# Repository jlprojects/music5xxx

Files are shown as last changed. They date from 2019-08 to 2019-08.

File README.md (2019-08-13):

# music5xxx
## Hybrid Music 5000/3000 BBC Microcomputer synthesiser clone PCB 

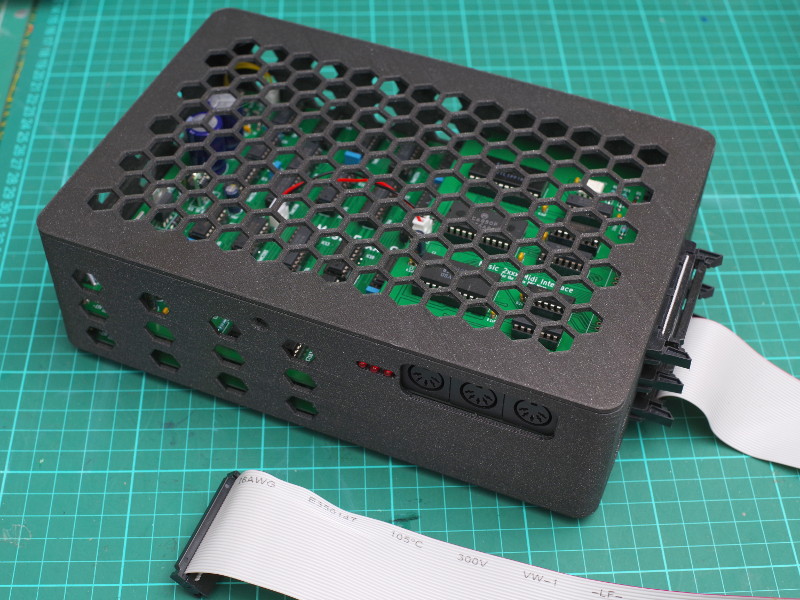
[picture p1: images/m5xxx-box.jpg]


This is a hardware clone of the Hybrid Music 5000 add-on for the BBC Microcomputer model B and Master 128. It was designed by Chris Jordan in 1984 as the Acorn Music500, and became part of quite an advanced (for its time) music recording and programming system. It was available for sale until at least 1992. Second hand models appear from time-to-time on eBay, but appear quite rare.

The unit connects to the BBC Microcomputer's 1Mhz bus, and implements an 8 voice, 16 channel, 8 bit stereo wavetable-style synthesizer. It uses a companding DAC to increase the fidelity of using 8 bit waveforms. The PCB can be configured as an expander, allowing two to be connected to the computer, doubling the available voices and channels.

## The clone

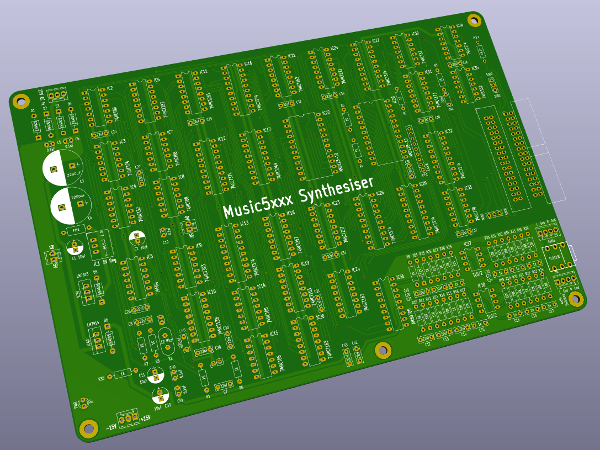
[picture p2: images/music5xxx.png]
music5xxx PCB render


It is designed in Kicad, using the original schematic and photographs of the original unit. PCBs have been made, and tested using a BBC Microcomputer Model B and BBC Master 128.

Currently all the 74xx series logic ICs are available new. Two 9128-10 RAM ICs, and the AM6070DC Companding DAC are no longer manufactured, but are available as NOS from Utsource https://www.utsource.net/ and perhaps other places.

Some alterations were made compared to the original unit:

* The power supply circuit has been changed for safety reasons, as the original unit used an on-board mains transformer. This is replaced by a 15V AC-AC plug-top adapter, and the +15V/-15V and 5V DC rails are generated from the 15V AC input. A LM7805 compatible switching DC-DC converter is used for the 5V rail, and saves having to use a heatsink if a linear adapter was used.

* Originally, the Music5000 used 74LS series logic ICs - experimentation has shown that 74HCT and 74HC series logic ICs can be used and work well with the circuit, with the advantage that they are more power efficient and run much cooler.

* The audio output DIN socket has been replaced with a 3.5mm stereo socket for convenience.

* The PCB can be configured using jumpers to work both as a Music5000 and Music3000 expander, allowing two PCBs to be stacked together sharing the same power supply.

* The low-pass filter in the output stage has been altered to not be so aggressive, possibly at the expense of unmasking some digital hash when using some instruments.

## Resources

* A comprehensive archive about the Hybrid Music System: https://www.retro-kit.co.uk/page.cfm/content/Hybrid-Music-5000-Synthesiser/

* The Stardot 8bit hardware forum often has posts about the Hybrid Music system: https://stardot.org.uk/forums/viewforum.php?f=3

* Here's the Stardot thread about this project: https://stardot.org.uk/forums/viewtopic.php?f=3&t=16895

## Other options

Instead of building one of these, you could use the emulated version that's included with Beebem: https://github.com/stardot/beebem-windows

Or if you want to use a real BBC Microcomputer you could make one of these:

* Hoglet's 1Mhz Bus->FPGA adapter which implements the Music5000/3000 in an FPGA module: https://stardot.org.uk/forums/viewtopic.php?f=3&t=16643

* dp11's 1Mhz Bus->Raspberry Pi adapter which emulates the Music5000 on a Raspberry Pi: https://stardot.org.uk/forums/viewtopic.php?f=3&t=15848

## Licence

Unless otherwise marked, work in this repository is licenced under [Creative Commons Attribution-ShareAlike 4.0 International License](http://creativecommons.org/licenses/by-sa/4.0/)

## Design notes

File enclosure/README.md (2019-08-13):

# music5xxx
## Hybrid Music 5000/3000/2000 BBC Microcomputer synthesiser clone project enclosure  

This is a design for a 3d printed enclosure for the clone Music5000 system. It is designed using Fusion360. STL files are provided for printing, as well as a Fusion360 file for modification.

music5xxx PCB render

It is designed for 3 PCBs separated using 15mm brass M-F spacers. The lowest PCB is configured as an M3000 module without the power supply components. The middle PCB is configured as a M5000 module. PCB headers and pins connect power between the two lower PCBs. The upper PCB is a [M2xxx Midi module](https://github.com/jlbeebprojects/music2xxx). A pair of wires connect to the 5V header on the M5000 PCB. 

I printed mine using 0.3mm layer height using PLA plastic. Make sure you have good bed adhesion to prevent warping due to the large flat contact areas. Note the design includes thin support struts to support the 1Mhz port and Midi output apertures. Clip these off before assembling the unit.

Insert and tighten the 15V AC power socket before installing the PCBs. 

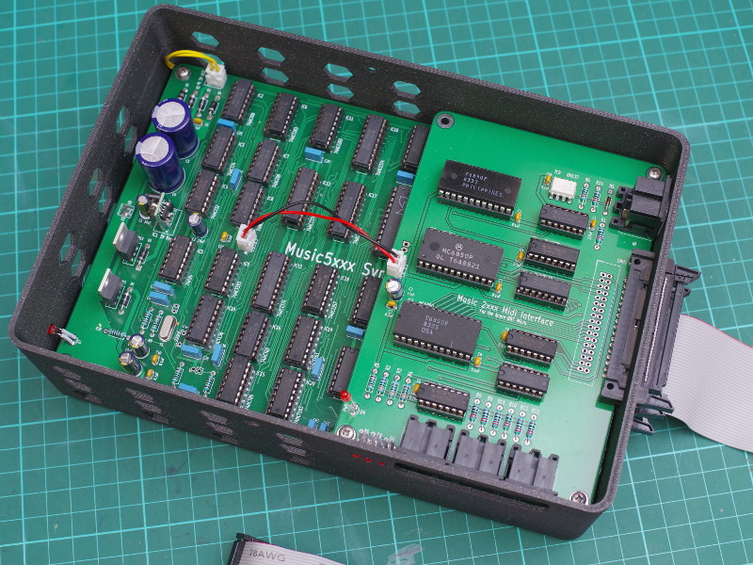
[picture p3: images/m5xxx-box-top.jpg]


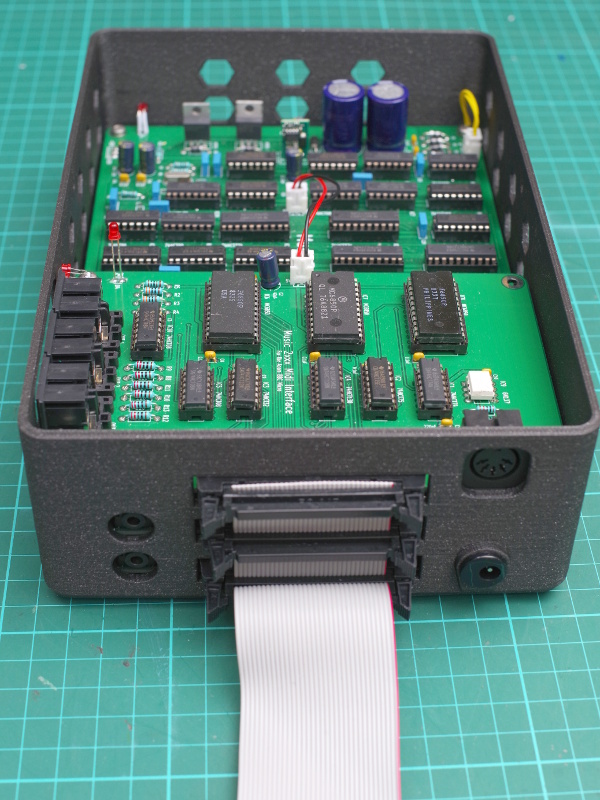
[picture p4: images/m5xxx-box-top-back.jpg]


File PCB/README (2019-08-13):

## Music 5xxx clone PCB

Made using Kicad 5.1.2

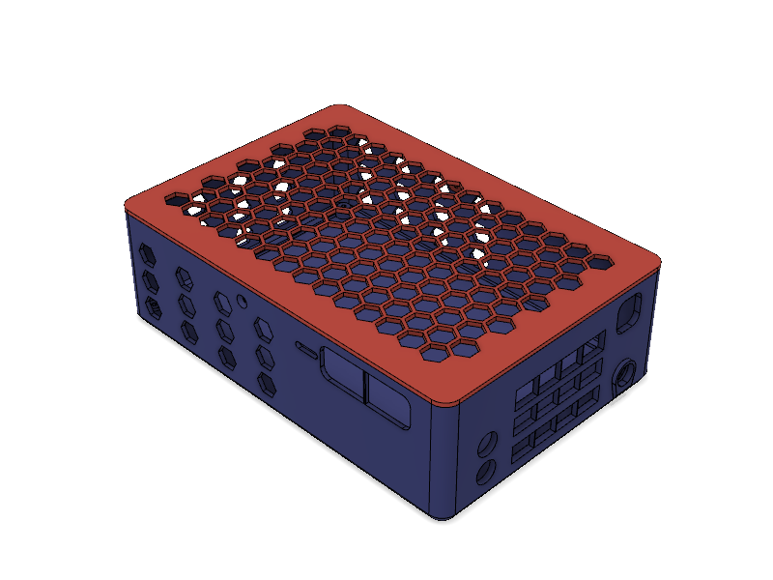
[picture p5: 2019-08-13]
enclosure/M5xxx-box.png

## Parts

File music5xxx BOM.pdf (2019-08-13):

music5xxx

## Music5xxx PCB BOM

Quantity Designation | Designator | Notes

Resistors
16 | 1K
1 | 4K7 | R37
21 | 15K
1 | 1Kx8 | RP1 | 9 pin resistor array, commoned

Capacitors
5 | 0.1uF | C5, C6, C10, C40, C41 | Ceramic: 2.5mm lead pitch
8 | 1n | C15, C16, C17, C18, C21, C22, C23, C24 Film: 5mm lead pitch
23 | 22nF | | Film: 5mm lead pitch
4 | 10uF | C1, C2, C11, C39 | Electrolytic 2.5mm lead pitch
2 | 2200uF | C3, C4 | Electrolytic 7.5mm lead pitch
Note: C9 (33pf, C44, C45 (220nF) not fitted

Diodes
6 | 1N4001 | D5, D6, D3, D4, D2, D1 | DO41
1 | PWR | D7 | 3mm LED
1 | 12V Zener Diode ZD1 | DO35

Integrated Circuits
1 | 74HCT00 | IC14
1 | 74F04 | IC5
3 | 74HCT08 | IC2, IC7, IC8
1 | 74HCT30 | IC33
3 | 74HCT32 | IC4, IC30, IC35
2 | 74HCT74 | IC33, IC33
1 | 74HCT86 | IC15
1 | 74HCT138 | IC10
4 | 74HCT163 | IC19, IC20, IC21, IC24
2 | 74HCT173 | IC15, IC31
1 | 74HCT244 | IC17
2 | 74HCT257 | IC18, IC23
2 | 74HCT283 | IC6, IC11
7 | 74HCT374
1 | 74HCT393 | IC9
2 | TL072 | IC37, IC38
1 | AM6070D | IC36
1 | R-78E5.0-1.0 | IC1
1 | LM7815 | IC39 | +15V Voltage regulator
1 | LM7915 | IC40 | -15V Voltage regulator
2 | AM9128-10 | IC22, IC28 | Memory IC

R1, R2, R3, R4, R5, R6, R7, R8, R9, R13, R15, R21, R25, R27, R33, R38

Standard 1% metal film through hole resistors

R10, R11, R12, R14, R16, R17, R18, R19, R20, R22, R23, R24, R26, R28, R29, R30, R31, R32, R34, R35, R36

C7, C8, C12, C13, C14, C19, C20, C25, C26, C27, C28, C29, C30, C31, C32, C33, C34, C35, C36, C37, C38, C42, C43

IC12, IC13, IC16, IC26, IC27, IC29, IC32

DC-DC converter – 1A, 7805 pinout switching module

music5xxx

IC Sockets
2 | 8 Way | 7.62mm wide
13 | 14 Way | 7.62mm wide
11 | 16 Way | 7.62mm wide
1 | 18 Way | 7.62mm wide
8 | 20 Way | 7.62mm wide
2 | 24 Way | Wide 15.24mm

Connectors – Molex KK/JST XH or similar
2 | J2, J3 | 2 way
1 | J1, J4 | 3 way
1 | J5, J6

1Mhz Bus connectors
1 | 1MHzBus1 | J11
1 | 1MHzBus2 | J12 IDC plugs for 1Mhz bus connection

Jack sockets
1 | FCR1295 | J7
1 | | Not on PCB

Misc
1 | 12 Mhz Crystal | X1 | Crystal HC49 Through hole
1 | Ferrite | FB1
13 | | 15mm hex standoffs, M3, male-female | Used for stacking boards

4 way – optional if using audio jack only

34 way (2x17) 2.54mm Straight IDC Header (use if connecting
extender/midi)
34 way (2x17) 2.54mm Angled IDC Header for 1Mhz Bus connection

34 way ribbon cable for 1Mz bus connection

Cliff FCR1295 stereo jack socket PCB mount
2.1mm panel
mount socket

Or suitable panel mount socket for 15V AC connection

Or use wire link. Ferrite helps isolate switcher supply noise.

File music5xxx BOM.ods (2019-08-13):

Music5xxx PCB BOM
Quantity | Designation | Designator | Notes
Resistors
16 | 1K | R1, R2, R3, R4, R5, R6, R7, R8, R9, R13, R15, R21, R25, R27, R33, R38 | Standard 1% metal film through hole resistors
1 | 4K7 | R37
21 | 15K | R10, R11, R12, R14, R16, R17, R18, R19, R20, R22, R23, R24, R26, R28, R29, R30, R31, R32, R34, R35, R36
1 | 1Kx8 | RP1 | 9 pin resistor array, commoned
Capacitors
5 | 0.1uF | C5, C6, C10, C40, C41 | Ceramic: 2.5mm lead pitch
8 | 1n | C15, C16, C17, C18, C21, C22, C23, C24 | Film: 5mm lead pitch
23 | 22nF | C7, C8, C12, C13, C14, C19, C20, C25, C26, C27, C28, C29, C30, C31, C32, C33, C34, C35, C36, C37, C38, C42, C43 | Film: 5mm lead pitch
4 | 10uF | C1, C2, C11, C39 | Electrolytic 2.5mm lead pitch
2 | 2200uF | C3, C4 | Electrolytic 7.5mm lead pitch
 |  | Note: C9 (33pf, C44, C45 (220nF) not fitted
Diodes
6 | 1N4001 | D5, D6, D3, D4, D2, D1 | DO41
1 | PWR | D7 | 3mm LED
1 | 12V Zener Diode | ZD1 | DO35
Integrated Circuits
1 | 74HCT00 | IC14
1 | 74F04 | IC5
3 | 74HCT08 | IC2, IC7, IC8
1 | 74HCT30 | IC33
3 | 74HCT32 | IC4, IC30, IC35
2 | 74HCT74 | IC33, IC33
1 | 74HCT86 | IC15
1 | 74HCT138 | IC10
4 | 74HCT163 | IC19, IC20, IC21, IC24
2 | 74HCT173 | IC15, IC31
1 | 74HCT244 | IC17
2 | 74HCT257 | IC18, IC23
2 | 74HCT283 | IC6, IC11
7 | 74HCT374 | IC12, IC13, IC16, IC26, IC27, IC29, IC32
1 | 74HCT393 | IC9
2 | TL072 | IC37, IC38
1 | AM6070D | IC36
1 | R-78E5.0-1.0 | IC1 | DC-DC converter – 1A, 7805 pinout switching module
1 | LM7815 | IC39 | +15V Voltage regulator
1 | LM7915 | IC40 | -15V Voltage regulator
2 | AM9128-10 | IC22, IC28 | Memory IC
IC Sockets
2 | 8 Way | 7.62mm wide
13 | 14 Way | 7.62mm wide
11 | 16 Way | 7.62mm wide
1 | 18 Way | 7.62mm wide
8 | 20 Way | 7.62mm wide
2 | 24 Way | Wide 15.24mm
Connectors – Molex KK/JST XH or similar
2 |  | J2, J3 | 2 way
1 |  | J1, J4 | 3 way
1 |  | J5, J6 | 4 way – optional if using audio jack only
1Mhz Bus connectors
1 | 1MHzBus1 | J11 | 34 way (2x17) 2.54mm Straight IDC Header (use if connecting extender/midi)
1 | 1MHzBus2 | J12 | 34 way (2x17) 2.54mm Angled IDC Header for 1Mhz Bus connection
 |  | IDC plugs for 1Mhz bus connection
 |  | 34 way ribbon cable for 1Mz bus connection
Jack sockets
1 | FCR1295 | J7 | Cliff FCR1295 stereo jack socket PCB mount
1 | 2.1mm panel mount socket | Not on PCB | Or suitable panel mount socket for 15V AC connection
Misc
1 | 12 Mhz Crystal | X1 | Crystal HC49 Through hole
1 | Ferrite | FB1 | Or use wire link. Ferrite helps isolate switcher supply noise.
13 |  | 15mm hex standoffs, M3, male-female | Used for stacking boards

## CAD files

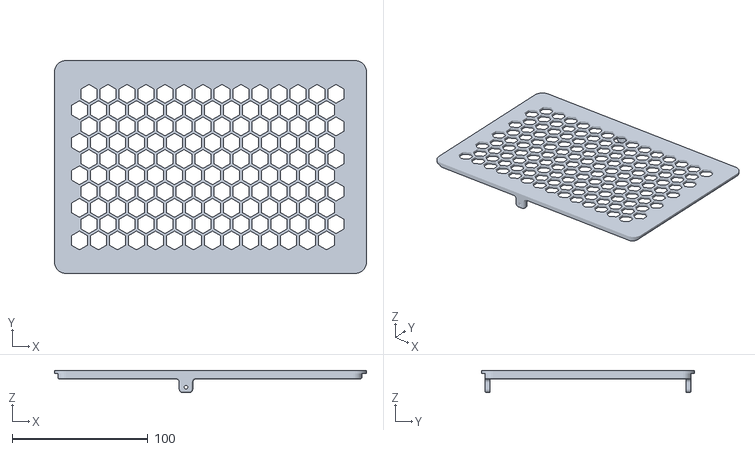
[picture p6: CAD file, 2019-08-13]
enclosure/M5xxx-lid.stl
229.8 x 156.8 x 16.4

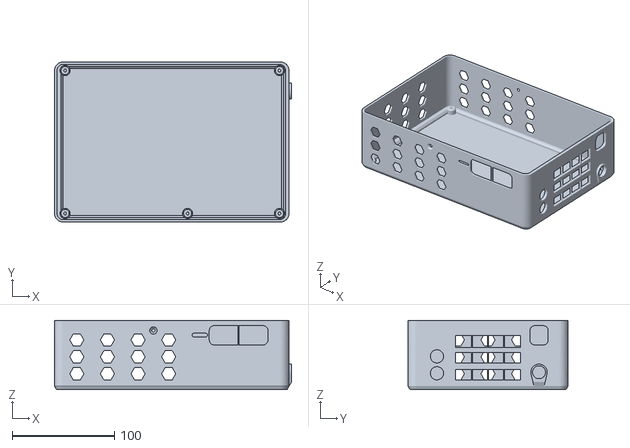
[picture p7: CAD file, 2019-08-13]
enclosure/M5xxx-base.stl
232.2 x 156.8 x 68.0

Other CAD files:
enclosure/M5xxx.f3d

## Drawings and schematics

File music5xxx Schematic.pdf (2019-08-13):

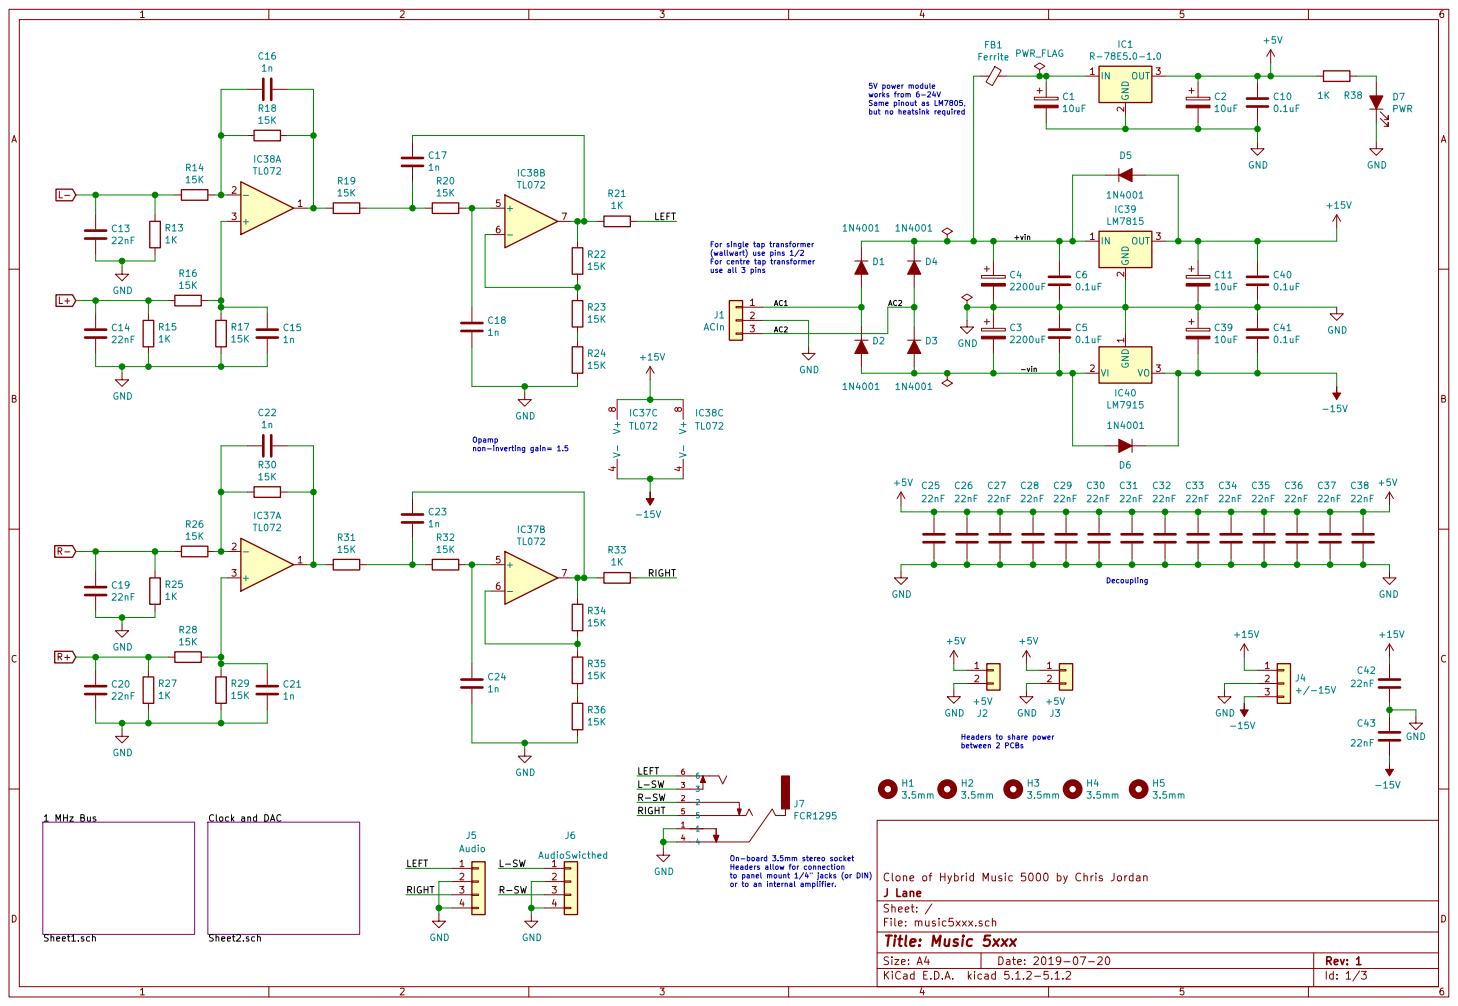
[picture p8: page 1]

Same pinout as LM7805, but no heatsink required +5V GND

5V power module works from 6-24V

For single tap transformer
(wallwart) use pins 1/2 For centre tap transformer use all 3 pins1

to panel mount 1/4" jacks (or DIN) or to an internal amplifier.

File: music5xxx.sch Sheet: / J Lane Clone of Hybrid Music 5000 by Chris Jordan

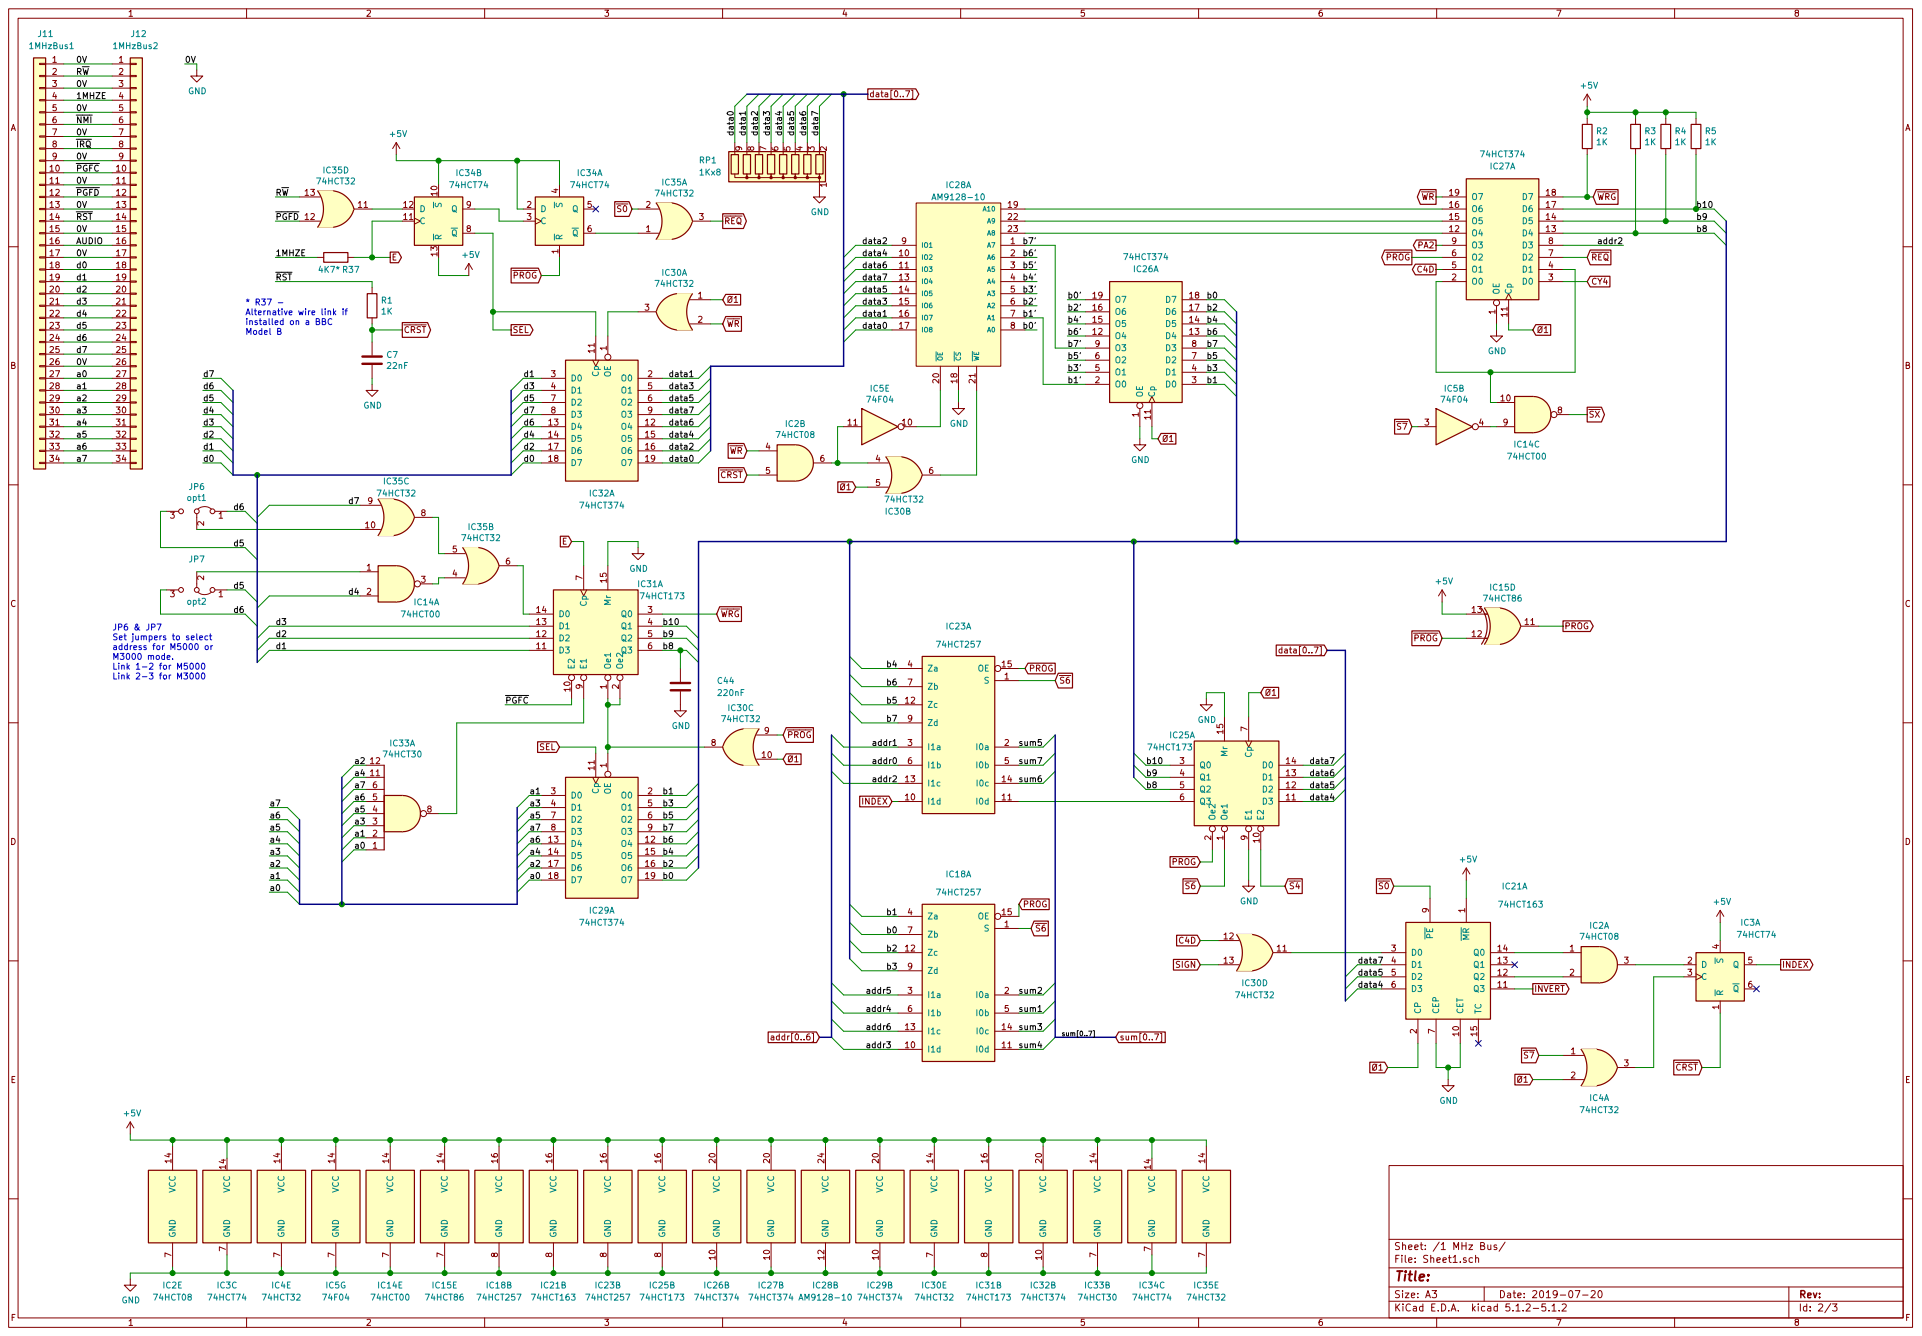
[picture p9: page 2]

* R37 - Alternative wire link if

installed on a BBC Model B

JP6 & JP7 Set jumpers to select address for M5000 or M3000 mode. Link 1-2 for M5000

Id: 2/3 Title: File: Sheet1.sch Sheet: /1 MHz Bus/

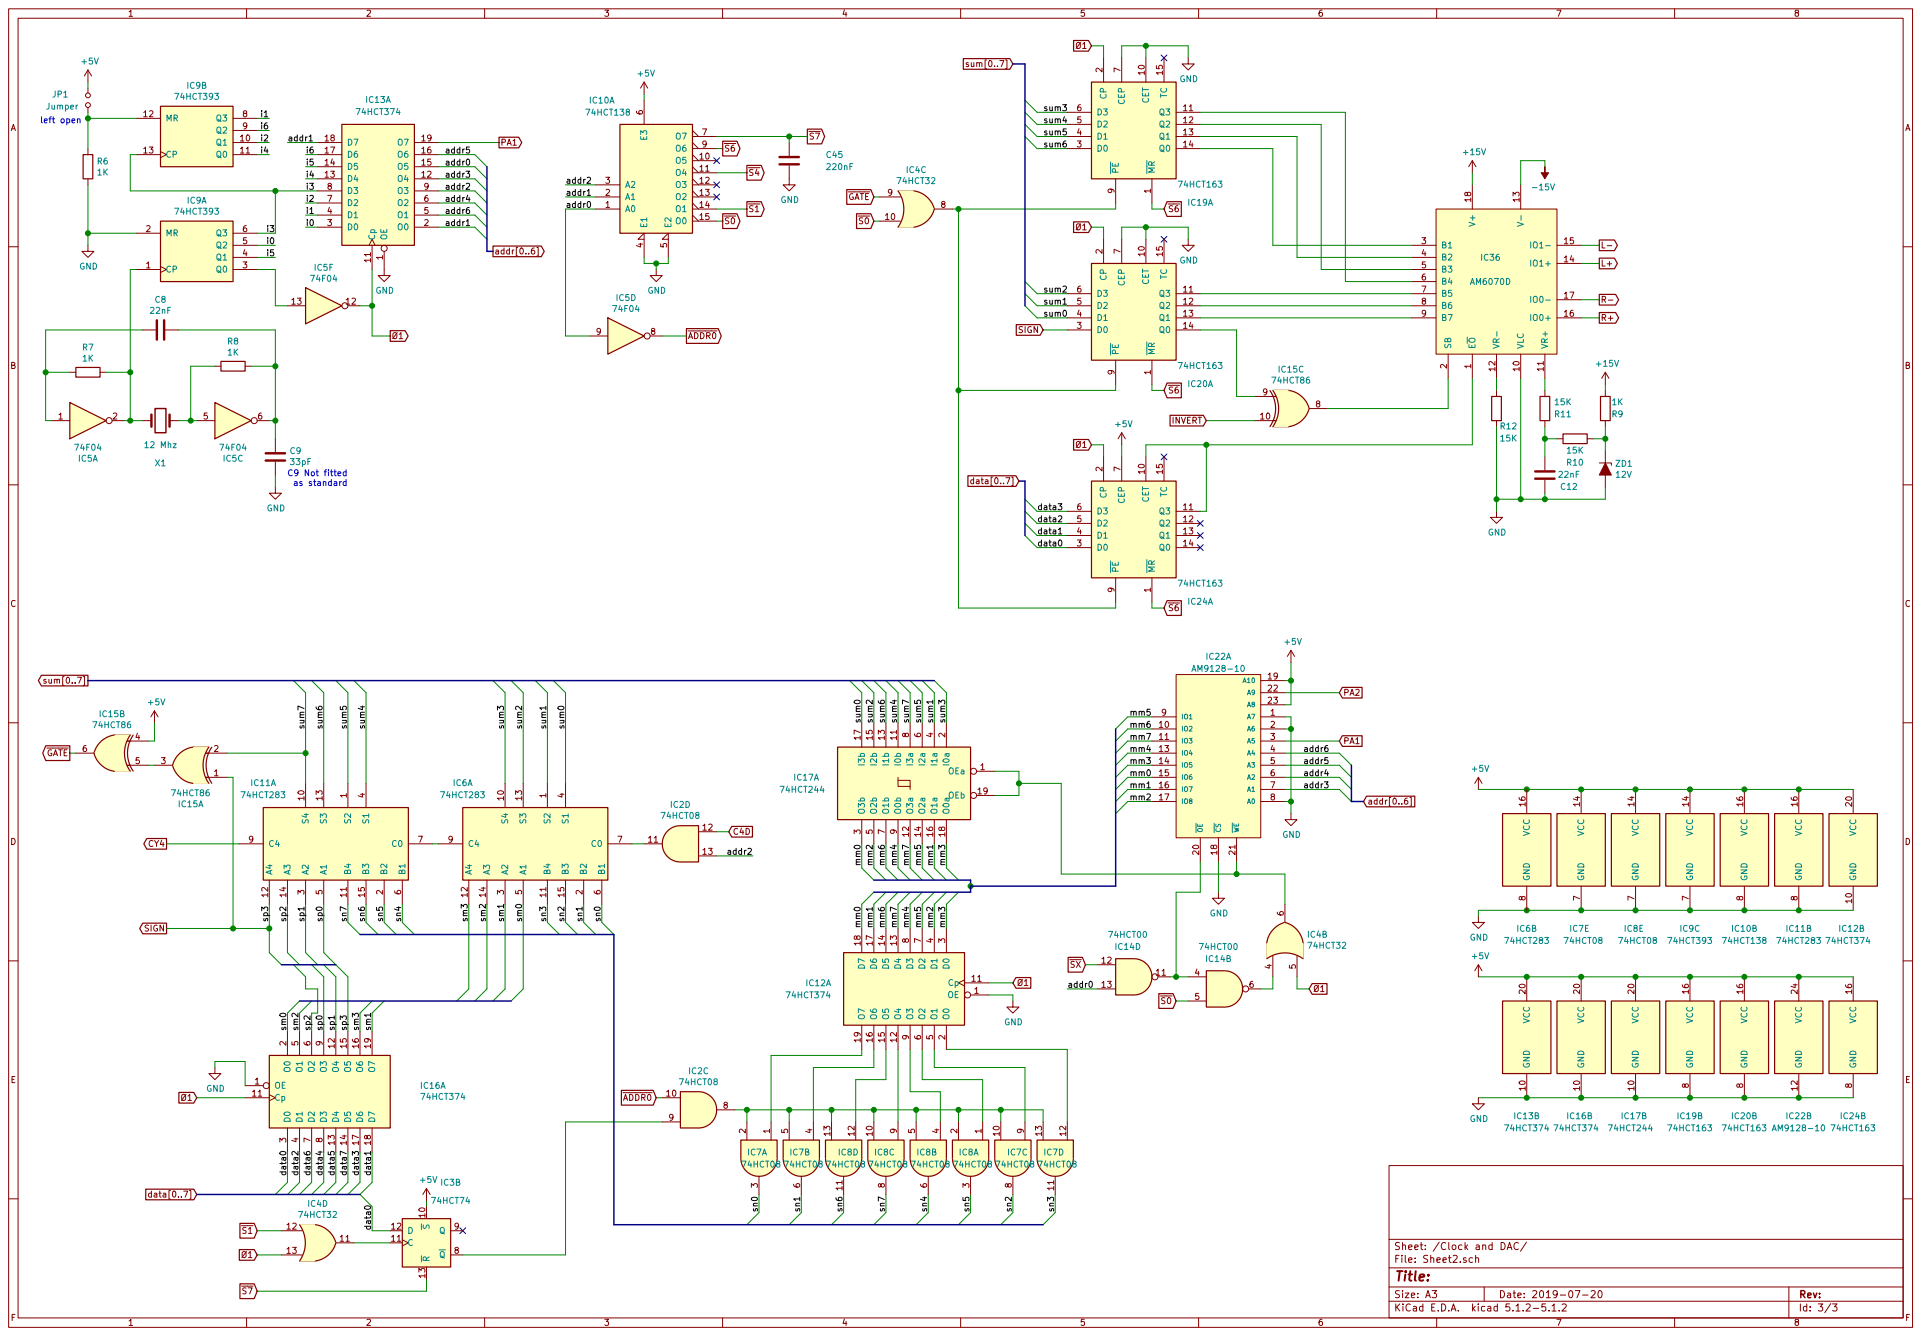
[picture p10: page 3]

Id: 3/3 Title: File: Sheet2.sch Sheet: /Clock and DAC/

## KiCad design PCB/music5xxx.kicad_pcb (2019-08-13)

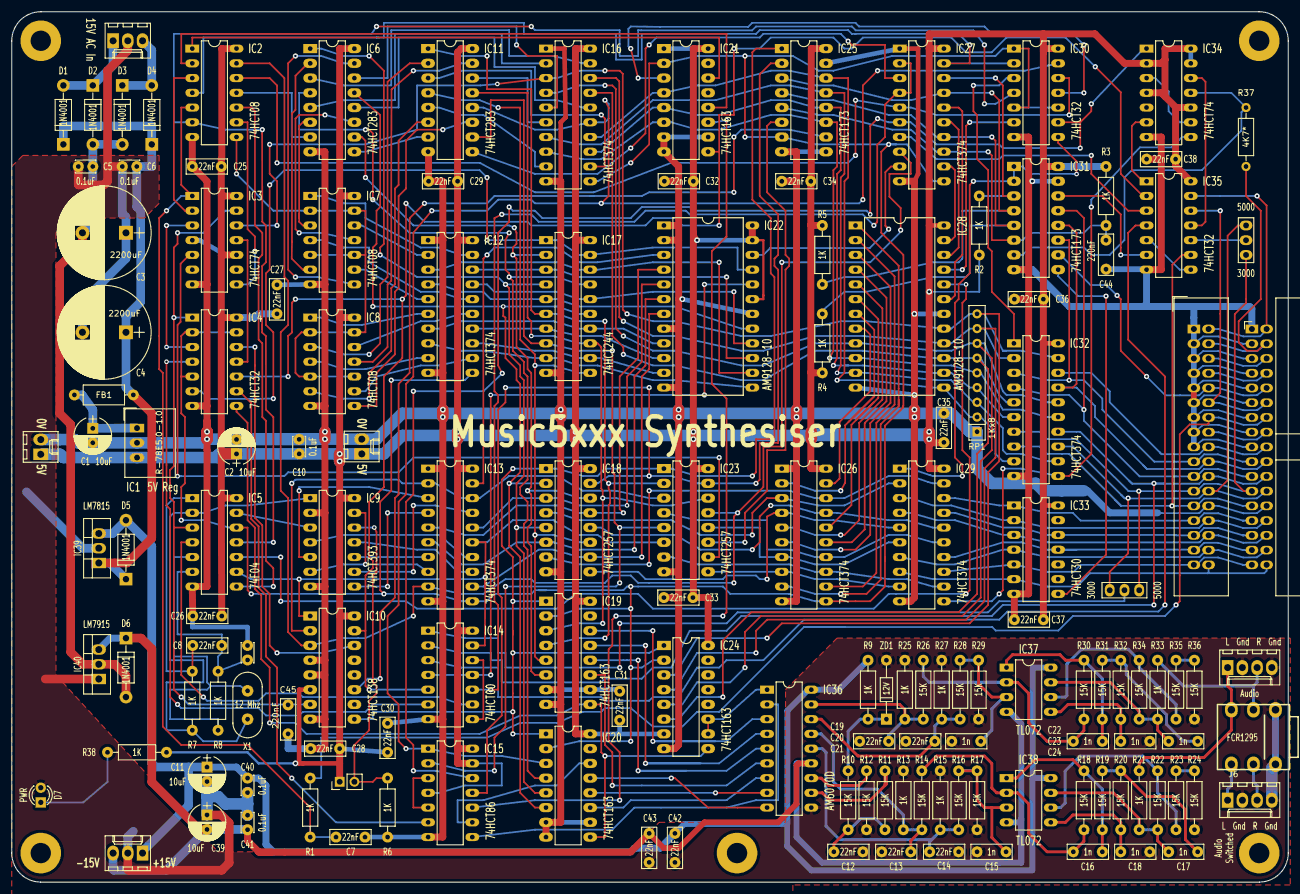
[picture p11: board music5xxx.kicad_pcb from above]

Board: 2 copper layers, 220.0 x 150.0 mm, 151 parts (0 on the bottom side), 217 nets.

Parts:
C1, C2, C11, C39: 10uF; CP_Radial_D6.3mm_P2.50mm
C3, C4: 2200uF; CP_Radial_D16.0mm_P7.50mm
C5, C6, C10, C40, C41: 0.1uF; C_Disc_D3.4mm_W2.1mm_P2.50mm
C7, C8, C12, C13, C14, C19, C20, C25, C26, C27, C28, C29, C30, C31, C32, C33, C34, C35, C36, C37, C38, C42, C43: 22nF; C_Rect_L7.0mm_W2.5mm_P5.00mm
C9: 33pF; C_Disc_D3.4mm_W2.1mm_P2.50mm
C15, C16, C17, C18, C21, C22, C23, C24: 1n; C_Rect_L7.0mm_W2.5mm_P5.00mm
C44, C45: 220nF; C_Rect_L7.0mm_W2.5mm_P5.00mm
D1, D2, D3, D4, D5, D6: 1N4001; D_DO-41_SOD81_P10.16mm_Horizontal
D7: PWR; LED_D3.0mm
FB1: Ferrite; L_Axial_L7.0mm_D3.3mm_P10.16mm_Horizontal_Fastron_MICC
H1, H2, H3, H4, H5: 3.5mm; MountingHole_3.5mm_Pad
IC1: R-78E5.0-1.0; DCDC-Conv_RECOM_R-78E-0.5
IC2, IC7, IC8: 74HCT08; DIP-14_W7.62mm_LongPads
IC3, IC34: 74HCT74; DIP-14_W7.62mm_LongPads
IC4, IC30, IC35: 74HCT32; DIP-14_W7.62mm_LongPads
IC5: 74F04; DIP-14_W7.62mm_LongPads
IC6, IC11: 74HCT283; DIP-16_W7.62mm_LongPads
IC9: 74HCT393; DIP-14_W7.62mm_LongPads
IC10: 74HCT138; DIP-16_W7.62mm_LongPads
IC12, IC13, IC16, IC26, IC27, IC29, IC32: 74HCT374; DIP-20_W7.62mm_LongPads
IC14: 74HCT00; DIP-14_W7.62mm_LongPads
IC15: 74HCT86; DIP-14_W7.62mm_LongPads
IC17: 74HCT244; DIP-20_W7.62mm_LongPads
IC18, IC23: 74HCT257; DIP-16_W7.62mm_LongPads
IC19, IC20, IC21, IC24: 74HCT163; DIP-16_W7.62mm_LongPads
IC22, IC28: AM9128-10; DIP-24_W15.24mm_LongPads
IC25, IC31: 74HCT173; DIP-16_W7.62mm_LongPads
IC33: 74HCT30; DIP-14_W7.62mm_LongPads
IC36: AM6070D; DIP-18_W7.62mm_LongPads
IC37, IC38: TL072; DIP-8_W7.62mm_LongPads
IC39: LM7815; TO-220-3_Vertical
IC40: LM7915; TO-220-3_Vertical
J1: ACIn; Molex_KK-6410-03_03x2.54mm_Straight
J2, J3: +5V; Molex_KK-6410-02_02x2.54mm_Straight
J4: +/-15V; Molex_KK-6410-03_03x2.54mm_Straight
J5: Audio; Molex_KK-6410-04_04x2.54mm_Straight
J6: AudioSwicthed; Molex_KK-6410-04_04x2.54mm_Straight
J7: FCR1295; Cliff-FCR1295
J11: 1MHzBus1; IDC-Header_2x17_Pitch2.54mm_Straight
J12: 1MHzBus2; IDC-Header_2x17_Pitch2.54mm_Angled
JP1: Jumper; Pin_Header_Straight_1x02_Pitch2.54mm
JP6: opt1; Pin_Header_Straight_1x03_Pitch2.54mm
JP7: opt2; Pin_Header_Straight_1x03_Pitch2.54mm
R1, R2, R3, R4, R5, R6, R7, R8, R9, R13, R15, R21, R25, R27, R33, R38: 1K; R_Axial_DIN0207_L6.3mm_D2.5mm_P10.16mm_Horizontal
R10, R11, R12, R14, R16, R17, R18, R19, R20, R22, R23, R24, R26, R28, R29, R30, R31, R32, R34, R35, R36: 15K; R_Axial_DIN0207_L6.3mm_D2.5mm_P10.16mm_Horizontal
R37: 4K7*; R_Axial_DIN0207_L6.3mm_D2.5mm_P10.16mm_Horizontal
RP1: 1Kx8; R_Array_SIP9
X1: 12 Mhz; Crystal_HC49-U_Vertical
ZD1: 12V; D_DO-35_SOD27_P10.16mm_Horizontal

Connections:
+5V: C2.1, C10.1, C25.1, C26.1, C27.1, C28.1, C29.1, C30.1, C31.1, C32.1, C33.1, C34.1, C35.1, C36.1, C37.1, C38.1, IC1.3, IC2.14, IC3.4, IC3.10, IC3.14, IC4.14, IC5.14, IC6.16, IC7.14, IC8.14, IC9.14, IC10.6, IC10.16, IC11.16, IC12.20, IC13.20, IC14.14, IC15.4, IC15.13, IC15.14, IC16.20, IC17.20, IC18.16, IC19.16, IC20.16, IC21.1, IC21.16, IC22.19, IC22.23, IC22.24, IC23.16, IC24.7, IC24.16, IC25.16, IC26.20, IC27.20, IC28.24, IC29.20, IC30.14, IC31.16, IC32.20, IC33.14, IC34.2, IC34.4, IC34.10, IC34.13, IC34.14, IC35.14, J2.1, J3.1, JP1.1, R2.1, R3.1, R4.1, R5.1, R38.1
+15V: C11.1, C40.1, C42.1, D5.2, IC36.18, IC37.8, IC38.8, IC39.3, J4.1, R9.2
-15V: C39.2, C41.2, C43.2, D6.1, IC36.13, IC37.4, IC38.4, IC40.3, J4.3
/1 MHz Bus/1MHZE: J11.4, J12.4, R37.2
/1 MHz Bus/AUDIO: J11.16, J12.16
/1 MHz Bus/R~W: IC35.13, J11.2, J12.2
/1 MHz Bus/a0: IC29.18, IC33.1, J11.27, J12.27
/1 MHz Bus/a1: IC29.3, IC33.2, J11.28, J12.28
/1 MHz Bus/a2: IC29.17, IC33.12, J11.29, J12.29
/1 MHz Bus/a3: IC29.4, IC33.3, J11.30, J12.30
/1 MHz Bus/a4: IC29.14, IC33.11, J11.31, J12.31
/1 MHz Bus/a5: IC29.7, IC33.4, J11.32, J12.32
/1 MHz Bus/a6: IC29.13, IC33.5, J11.33, J12.33
/1 MHz Bus/a7: IC29.8, IC33.6, J11.34, J12.34
/1 MHz Bus/b0: IC18.7, IC26.18, IC29.19
/1 MHz Bus/b0': IC26.19, IC28.8
/1 MHz Bus/b1: IC18.4, IC26.3, IC29.2
/1 MHz Bus/b1': IC26.2, IC28.7
/1 MHz Bus/b2: IC18.12, IC26.17, IC29.16
/1 MHz Bus/b2': IC26.16, IC28.6
/1 MHz Bus/b3: IC18.9, IC26.4, IC29.5
/1 MHz Bus/b3': IC26.5, IC28.5
/1 MHz Bus/b4: IC23.4, IC26.14, IC29.15
/1 MHz Bus/b4': IC26.15, IC28.4
/1 MHz Bus/b5: IC23.12, IC26.7, IC29.6
/1 MHz Bus/b5': IC26.6, IC28.3
/1 MHz Bus/b6: IC23.7, IC26.13, IC29.12
/1 MHz Bus/b6': IC26.12, IC28.2
/1 MHz Bus/b7: IC23.9, IC26.8, IC29.9
/1 MHz Bus/b7': IC26.9, IC28.1
/1 MHz Bus/b8: C44.1, IC25.5, IC27.13, IC31.6, R3.2
/1 MHz Bus/b9: IC25.4, IC27.14, IC31.5, R4.2
/1 MHz Bus/b10: IC25.3, IC27.17, IC31.4, R5.2
/1 MHz Bus/d0: IC32.18, J11.18, J12.18
/1 MHz Bus/d1: IC31.11, IC32.3, J11.19, J12.19
/1 MHz Bus/d2: IC31.12, IC32.17, J11.20, J12.20
/1 MHz Bus/d3: IC31.13, IC32.4, J11.21, J12.21
/1 MHz Bus/d4: IC14.2, IC32.14, J11.22, J12.22
/1 MHz Bus/d5: IC32.7, J11.23, J12.23, JP6.3, JP7.1
/1 MHz Bus/d6: IC32.13, J11.24, J12.24, JP6.1, JP7.3
/1 MHz Bus/d7: IC32.8, IC35.9, J11.25, J12.25
/1 MHz Bus/~IRQ: J11.8, J12.8
/1 MHz Bus/~NMI: J11.6, J12.6
/1 MHz Bus/~PGFC: IC31.10, J11.10, J12.10
/1 MHz Bus/~PGFD: IC35.12, J11.12, J12.12
/1 MHz Bus/~RST: J11.14, J12.14, R1.1
/+vin: C4.1, C6.1, D1.1, D4.1, D5.1, FB1.2, IC39.1
/-vin: C3.2, C5.2, D2.2, D3.2, D6.2, IC40.2
/AC1: D1.2, D2.1, J1.1
/AC2: D3.1, D4.2, J1.3
/Clock and DAC/i0: IC9.5, IC13.3
/Clock and DAC/i1: IC9.8, IC13.4
/Clock and DAC/i2: IC9.10, IC13.7
/Clock and DAC/i3: IC9.6, IC9.13, IC13.8
/Clock and DAC/i4: IC9.11, IC13.13
/Clock and DAC/i5: IC9.4, IC13.14
/Clock and DAC/i6: IC9.9, IC13.17
/Clock and DAC/mm0: IC12.18, IC17.3, IC22.15
/Clock and DAC/mm1: IC12.17, IC17.16, IC22.16
/Clock and DAC/mm2: IC12.4, IC17.5, IC22.17
/Clock and DAC/mm3: IC12.3, IC17.18, IC22.14
/Clock and DAC/mm4: IC12.8, IC17.9, IC22.13
/Clock and DAC/mm5: IC12.7, IC17.14, IC22.9
/Clock and DAC/mm6: IC12.14, IC17.7, IC22.10
/Clock and DAC/mm7: IC12.13, IC17.12, IC22.11
/Clock and DAC/sm0: IC6.5, IC16.2
/Clock and DAC/sm1: IC6.3, IC16.19
/Clock and DAC/sm2: IC6.14, IC16.5
/Clock and DAC/sm3: IC6.12, IC16.16
/Clock and DAC/sn0: IC6.6, IC7.3
/Clock and DAC/sn1: IC6.2, IC7.6
/Clock and DAC/sn2: IC6.15, IC7.8
/Clock and DAC/sn3: IC6.11, IC7.11
/Clock and DAC/sn4: IC8.6, IC11.6
/Clock and DAC/sn5: IC8.3, IC11.2
/Clock and DAC/sn6: IC8.11, IC11.15
/Clock and DAC/sn7: IC8.8, IC11.11
/Clock and DAC/sp0: IC11.5, IC16.9
/Clock and DAC/sp1: IC11.3, IC16.12
/Clock and DAC/sp2: IC11.14, IC16.6
/L-SW: J6.1, J7.3
/LEFT: J5.1, J7.6, R21.2
/R-SW: J6.3, J7.2
/RIGHT: J5.3, J7.5, R33.2
C4D: IC2.12, IC27.5, IC30.12
CY4: IC11.9, IC27.3
E: IC31.7, IC34.11, R37.1
GND: C1.2, C2.2, C3.1, C4.2, C5.1, C6.2, C7.2, C9.1, C10.2, C11.2, C12.1, C13.2, C14.2, C15.2, C18.1, C19.2, C20.2, C21.2, C24.1, C25.2, C26.2, C27.2, C28.2, C29.2, C30.2, C31.2, C32.2, C33.2, C34.2, C35.2, C36.2, C37.2, C38.2, C39.1, C40.2, C41.1, C42.2, C43.1, C44.2, C45.2, D7.1, IC1.2, IC2.7, IC3.7, IC4.7, IC5.7, IC6.8, IC7.7, IC8.7, IC9.2, IC9.7, IC10.4, IC10.5, IC10.8, IC11.8, IC12.1, IC12.10, IC13.1, IC13.10, IC14.7, IC15.7, IC16.1, IC16.10, IC17.10, IC18.8, IC19.7, IC19.8, IC19.10, IC20.7, IC20.8, IC20.10, IC21.7, IC21.8, IC21.10, IC22.1, IC22.2, IC22.8, IC22.12, IC22.18, IC23.8, IC24.8, IC25.8, IC25.9, IC25.15, IC26.1, IC26.10, IC27.1, IC27.10, IC28.12, IC28.18, IC29.10, IC30.7, IC31.8, IC31.15, IC32.10, IC33.7, IC34.7, IC35.7, IC36.10, IC39.2, IC40.1, J1.2, J2.2, J3.2, J4.2, J5.2, J5.4, J6.2, J6.4, J7.1, J7.4, J11.1, J11.3, J11.5, J11.7, J11.9, J11.11, J11.13, J11.15, J11.17, J11.26, J12.1, J12.3, J12.5, J12.7, J12.9, J12.11, J12.13, J12.15, J12.17, J12.26, R6.2, R12.1, R13.1, R15.1, R17.1, R24.1, R25.1, R27.1, R29.1, R36.1, RP1.1, ZD1.2
INDEX: IC3.5, IC23.10
INVERT: IC15.10, IC21.11
L+: C14.1, IC36.14, R15.2, R16.2
L-: C13.1, IC36.15, R13.2, R14.2
unnamed: C1.1, FB1.1, IC1.1
unnamed: C8.1, C9.2, IC5.6, R8.1
unnamed: C8.2, IC5.1, R7.2
unnamed: C12.2, R10.1, R11.1
unnamed: C15.1, IC38.3, R16.1, R17.2
unnamed: C16.1, IC38.1, R18.1, R19.2
unnamed: C16.2, IC38.2, R14.1, R18.2
unnamed: C17.1, R19.1, R20.2
unnamed: C17.2, IC38.7, R21.1, R22.2
unnamed: C18.2, IC38.5, R20.1
unnamed: C21.1, IC37.3, R28.1, R29.2
unnamed: C22.1, IC37.1, R30.1, R31.2
unnamed: C22.2, IC37.2, R26.1, R30.2
unnamed: C23.1, R31.1, R32.2
unnamed: C23.2, IC37.7, R33.1, R34.2
unnamed: C24.2, IC37.5, R32.1
unnamed: D7.2, R38.2
unnamed: IC2.1, IC21.14
unnamed: IC2.2, IC21.12
unnamed: IC2.3, IC3.2
unnamed: IC2.6, IC5.11, IC30.4
unnamed: IC2.8, IC7.2, IC7.5, IC7.10, IC7.13, IC8.2, IC8.5, IC8.10, IC8.13
unnamed: IC2.9, IC3.8
unnamed: IC2.11, IC6.7
unnamed: IC3.3, IC4.3
unnamed: IC3.11, IC4.11
unnamed: IC5.2, IC9.1, R7.1, X1.1
unnamed: IC5.5, R8.2, X1.2
unnamed: IC5.13, IC9.3
unnamed: IC9.12, JP1.2, R6.1
unnamed: IC6.9, IC11.7
unnamed: IC7.12, IC12.2
unnamed: IC7.9, IC12.5
unnamed: IC8.1, IC12.6
unnamed: IC8.4, IC12.9
unnamed: IC8.9, IC12.12
unnamed: IC8.12, IC12.15
unnamed: IC7.4, IC12.16
unnamed: IC7.1, IC12.19
unnamed: IC14.1, JP7.2
unnamed: IC14.3, IC35.4
unnamed: IC4.4, IC14.6
unnamed: IC5.4, IC14.9
unnamed: IC14.10, IC27.2, IC27.4
unnamed: IC14.4, IC14.11, IC22.20
unnamed: IC15.3, IC15.5
unnamed: IC15.8, IC36.2
unnamed: IC15.9, IC20.14
unnamed: IC4.6, IC17.1, IC17.19, IC22.21
unnamed: IC4.8, IC19.9, IC20.9, IC24.9
unnamed: IC19.11, IC36.6
unnamed: IC19.12, IC36.5
unnamed: IC19.13, IC36.4
unnamed: IC19.14, IC36.3
unnamed: IC20.11, IC36.7
unnamed: IC20.12, IC36.8
unnamed: IC20.13, IC36.9
unnamed: IC21.3, IC30.11
unnamed: IC23.11, IC25.6
unnamed: IC24.10, IC24.11, IC36.1
unnamed: IC27.12, IC28.23
unnamed: IC27.15, IC28.22
unnamed: IC27.16, IC28.19
unnamed: IC5.10, IC28.20
unnamed: IC28.21, IC30.6
unnamed: IC29.1, IC30.8, IC31.1, IC31.2
unnamed: IC30.3, IC32.1
unnamed: IC31.9, IC33.8
unnamed: IC31.14, IC35.6
unnamed: IC34.3, IC34.9
unnamed: IC34.6, IC35.1
unnamed: IC34.12, IC35.11
unnamed: IC35.5, IC35.8
unnamed: IC35.10, JP6.2
unnamed: IC36.11, R11.2
unnamed: IC36.12, R12.2
unnamed: IC37.6, R34.1, R35.2
unnamed: IC38.6, R22.1, R23.2
unnamed: R9.1, R10.2, ZD1.1
unnamed: R23.1, R24.2
unnamed: R35.1, R36.2
PA1: IC13.19, IC22.3
PA2: IC22.22, IC27.9
PROG: IC15.11, IC18.15, IC23.15, IC25.2
R+: C20.1, IC36.16, R27.2, R28.2
R-: C19.1, IC36.17, R25.2, R26.2
SEL: IC29.11, IC32.11, IC34.8
SIGN: IC11.12, IC15.1, IC16.15, IC20.3, IC30.13
addr0: IC5.9, IC10.1, IC13.15, IC14.13, IC23.6
addr1: IC10.2, IC13.2, IC13.18, IC23.3
addr2: IC2.13, IC10.3, IC13.9, IC23.13, IC27.8
addr3: IC13.12, IC18.10, IC22.7
addr4: IC13.6, IC18.6, IC22.6
addr5: IC13.16, IC18.3, IC22.5
addr6: IC13.5, IC18.13, IC22.4
data0: IC3.12, IC16.3, IC24.3, IC28.17, IC32.19, RP1.9
data1: IC16.18, IC24.4, IC28.16, IC32.2, RP1.8
data2: IC16.4, IC24.5, IC28.9, IC32.16, RP1.7
data3: IC16.17, IC24.6, IC28.15, IC32.5, RP1.6
data4: IC16.8, IC21.6, IC25.11, IC28.10, IC32.15, RP1.5
data5: IC16.13, IC21.5, IC25.12, IC28.14, IC32.6, RP1.4
data6: IC16.7, IC25.13, IC28.11, IC32.12, RP1.3
data7: IC16.14, IC21.4, IC25.14, IC28.13, IC32.9, RP1.2
sum0: IC6.4, IC17.17, IC20.4
sum1: IC6.1, IC17.4, IC18.5, IC20.5
sum2: IC6.13, IC17.15, IC18.2, IC20.6
sum3: IC6.10, IC17.2, IC18.14, IC19.6
sum4: IC11.4, IC17.11, IC18.11, IC19.5
sum5: IC11.1, IC17.6, IC19.4, IC23.2
sum6: IC11.13, IC17.13, IC19.3, IC23.14
sum7: IC11.10, IC15.2, IC17.8, IC23.5
~ADDR0: IC2.10, IC5.8
~CRST: C7.1, IC2.5, IC3.1, R1.2
~GATE: IC4.9, IC15.6
~PROG: IC15.12, IC27.6, IC30.9, IC34.1
~REQ: IC27.7, IC35.3
~S0: IC4.10, IC10.15, IC14.5, IC21.9, IC35.2
~S1: IC4.12, IC10.14
~S4: IC10.11, IC25.10
~S6: IC10.9, IC18.1, IC19.1, IC20.1, IC23.1, IC24.1, IC25.1
~S7: C45.1, IC3.13, IC4.1, IC5.3, IC10.7
~SX: IC14.8, IC14.12
~WR: IC2.4, IC27.19, IC30.2
~WRG: IC27.18, IC31.3, R2.2
Ø1: IC4.2, IC4.5, IC4.13, IC5.12, IC12.11, IC13.11, IC16.11, IC19.2, IC20.2, IC21.2, IC24.2, IC25.7, IC26.11, IC27.11, IC30.1, IC30.5, IC30.10

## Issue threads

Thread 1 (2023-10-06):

Schematic title

chrisjj, 2023-10-06:
https://i.imgur.com/I18C2Ir.png

Perhaps clarify to avoid the impression the clone is by Chris Jordan.

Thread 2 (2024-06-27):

R37 + caps need to be fitted so that board works with Master 128

PacificState, 2024-06-27:
I couldn't get my build to work with a Master 128 initially. Per the thread @ https://www.stardot.org.uk/forums/viewtopic.php?p=429079#p429079, the value of R37 needs to be changed to 470 Ohm, and 220pF caps fitted.
